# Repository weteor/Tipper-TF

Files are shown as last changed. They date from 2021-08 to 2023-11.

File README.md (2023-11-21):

# Tipper-TF
34 keys split unibody BLE keyboard. 

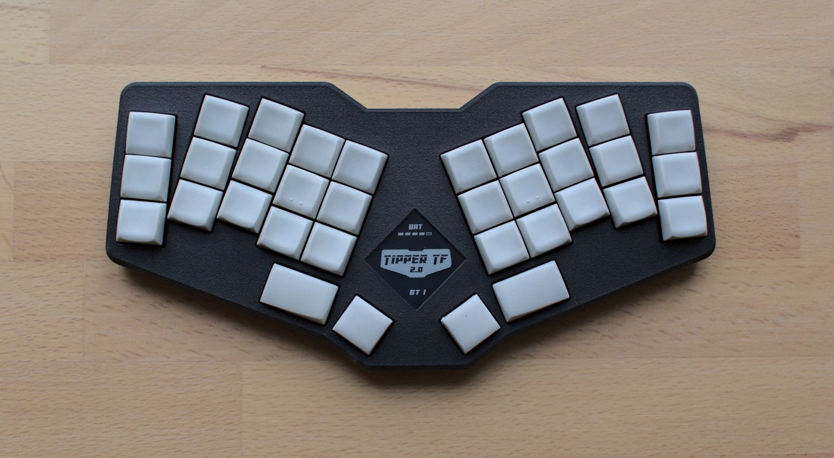
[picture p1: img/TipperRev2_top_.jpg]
top


## Features

- low profile
- choc v1 w/ choc spacing
- angled hands
- splayed columns
- variable height on outer colum. Can be adjusted by a combination of pinheaders(1.27mm pitch, 1mm or 1.5mm height) + (at the moment) spacer pcbs.
- 1.54'' epaper display (Good Display GDEW0154M09)
- Bluetooth and USB connection 
- case files are supplied (stl, as well as freecad files)
- ZMK firmware support

## Want one?
All production files you need to build your own Tipper TF can be found [here](https://github.com/weteor/Tipper-TF/tree/main/production).

Please see the [build instruction](https://github.com/weteor/Tipper-TF/tree/main/production/build_instructions.md) for a more detailed listing of all things needed.

All PCBs come with SMT assembly files, so you can order them fully assembled. No need to solder another 50 diodes.

The files for the case are also provided. If you don't own a 3d printer, I've used JLCPCBs printing service (MJF nylon) and it turned out very good, so maybe take a look at that option.

### firmware 
The Tipper TF uses ZMK firmware.

The zmk driver for the display driver chip is not in the official repository yet, so you will have to use [my ZMK fork](https://github.com/weteor/zmk/tree/Tipper_TF_rev2) if you want to build a firmware locally.

If you prefer the github workflow, you can find the zmk config for the Tipper TF [here](https://github.com/weteor/Tipper_TF-Config). The config is already configured to pull ZMK from my fork, so you don't have to do anything further.

### some more pictures
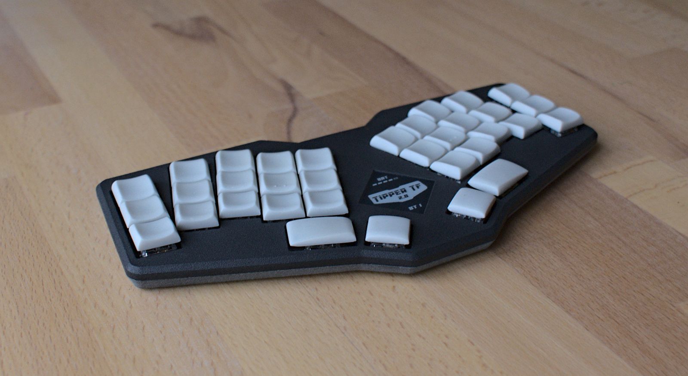
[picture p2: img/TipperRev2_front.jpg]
front

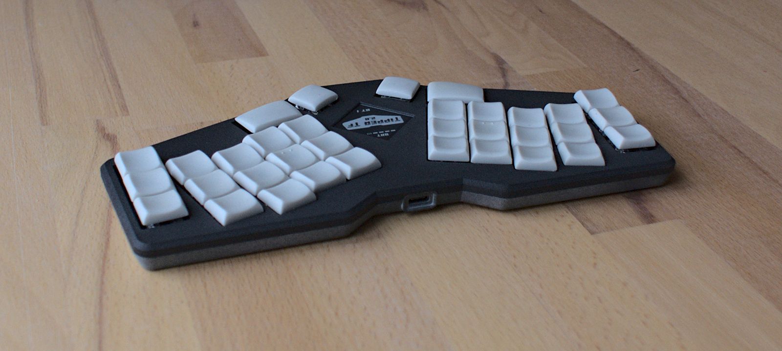
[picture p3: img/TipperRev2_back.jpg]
back


## remarks
MKB keycaps work great on the Tipper, but I very much prefer the Chicago Steno caps by Pseudoku. He provides some nice SCAD files for those, you may find them in [his github](https://github.com/pseudoku/PseudoMakeMeKeyCapProfiles). He also sells them in his shop [www.asymplex.xyz](https://www.asymplex.xyz/).

### thanks for help and inspiration:
- [MangoIV](https://github.com/MangoIV/) and his [le-chiffre-ble](https://github.com/MangoIV/le_chiff_ble)
- [broom's](https://github.com/davidphilipbarr) [hypergolic](https://github.com/davidphilipbarr/hypergolic)
- [marv](https://github.com/MarvFPV) invaluable feedback and help with the case design

## the rest
Everything in this repository is free to use however you might see fit. If you want to support me and my projects, please consider linking back to this repository if you build/change/use anything. 

If you would like to send me a tip, you could do it [here](https://ko-fi.com/weteor) (Please don't feel like you have to).

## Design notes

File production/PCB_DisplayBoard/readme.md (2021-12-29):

## PCB
Gerber and drill files -> [GERBER_DisplayDaughterboardEPD.zip](https://github.com/weteor/Tipper-TF/blob/main/production/PCB_DisplayBoard/GERBER_DisplayDaughterboardEPD.zip)

#### Production Parameters:

- Layers: 2
- PCB Thickness: **1.2mm**
- Dimensions: 44.6 mm* 40.1 mm
- Designs: 1

## SMT Assembly 

The files are specifically made for JLCPCB, but with some small modifications should be usable with every other SMTA service.

BOM file -> [BOM_DisplayDaughterboardEPD.csv](https://github.com/weteor/Tipper-TF/blob/main/production/PCB_DisplayBoard/BOM_DisplayDaughterboardEPD.csv)

component placement file -> [POS_DisplayDaughterboardEPD.csv](https://github.com/weteor/Tipper-TF/blob/main/production/PCB_DisplayBoard/POS_DisplayDaughterboardEPD.csv)

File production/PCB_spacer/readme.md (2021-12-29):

## PCB
Gerber and drill files -> [spacerPcb.zip](https://github.com/weteor/Tipper-TF/blob/main/production/PCB_spacer/spacerPcb.zip)

#### Production Parameters:

- Layers: 2
- PCB Thickness: depends, recommended are at least **0.8mm** and **1.0mm**
- Dimensions: 48 mm* 14 mm
- Designs: 1

## remarks
spacer pcbs can be stacked do get the desired height of the pinky column. I prefer 1.8mm, so i use 0.8 and 1.0mm spacer pcbs. 

Heights up to 2mm can be realized with just pcb spacers. The switches can still be soldered directly on the backside of the main pcb. If a higher level is
needed, you have to use 1.27mm pitched pin headers under the spacer pcb.

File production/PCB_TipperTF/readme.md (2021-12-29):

## PCB
Gerber and drill files -> [TipperTF.zip](https://github.com/weteor/Tipper-TF/blob/main/production/PCB_TipperTF/TipperTF.zip)

#### Production Parameters:

- Layers: 2
- PCB Thickness: **1.2mm**
- Dimensions: 229.6 mm* 104.4 mm
- Designs: 1

## SMT Assembly 

The files are specifically made for JLCPCB, but with some small modifications should be usable with every other SMTA service.

BOM file -> [TipperTF.csv](https://github.com/weteor/Tipper-TF/blob/main/production/PCB_TipperTF/TipperTF.csv)

component placement file -> [TipperTF-top-pos.csv](https://github.com/weteor/Tipper-TF/blob/main/production/PCB_TipperTF/TipperTF-top-pos.csv)

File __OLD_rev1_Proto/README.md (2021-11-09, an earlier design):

# Tipper-TF
34 keys split unibody BLE keyboard. 

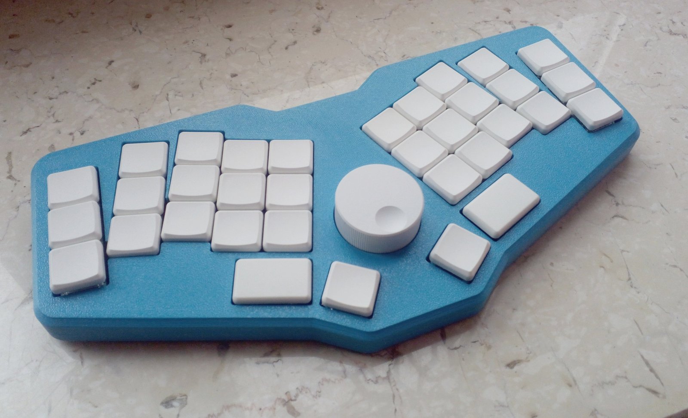
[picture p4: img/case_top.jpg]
front

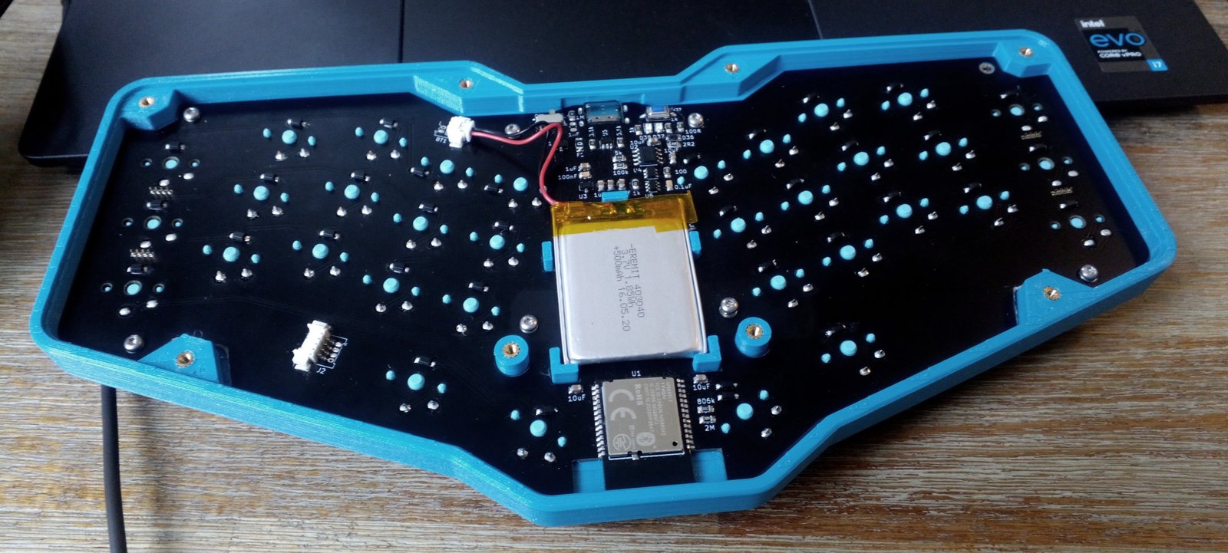
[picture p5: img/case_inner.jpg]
back


- low profile
- choc v1
- central rotary encoder
- angled hands
- splayed columns
- variable height on outer colum. Can be adjusted by a combination of pinheaders(1.27mm pitch, 1mm or 1.5mm height) + (at the moment) 0.8mm spacer pcbs.
- BLE
- case files are supplied

## all files are considered untested prototypes, please don't use them to make your own board just yet. 
At the minimum there is a mismatch between pcb outlines and the case files. pcb needs some small fixes, too

### firmware 
ZMK, config can be found [here](https://github.com/weteor/Tipper_TF-Config)

### thanks for help and inspiration:
- [MangoIV](https://github.com/MangoIV/) and his [le-chiffre-ble](https://github.com/MangoIV/le_chiff_ble)
- [broom's](https://github.com/davidphilipbarr) [hypergolic](https://github.com/davidphilipbarr/hypergolic)
- [marv](https://github.com/MarvFPV) invaluable feedback and help with the case design

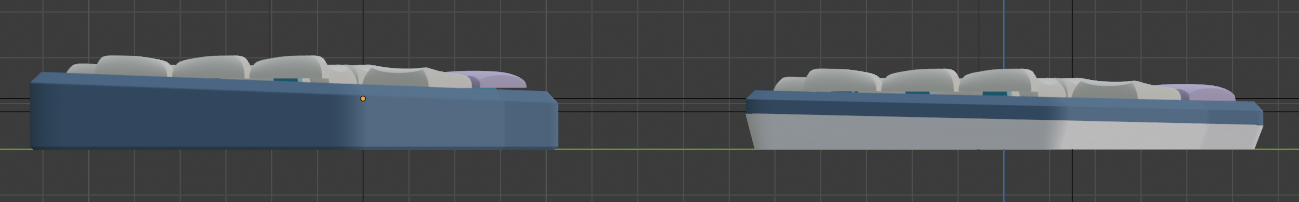
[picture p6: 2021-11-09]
img/proto_rev2_comparison_side.png

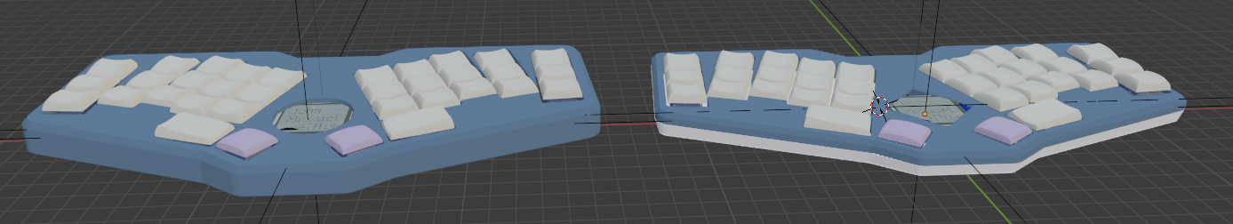
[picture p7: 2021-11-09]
img/proto_rev2_comparison_front_2.png

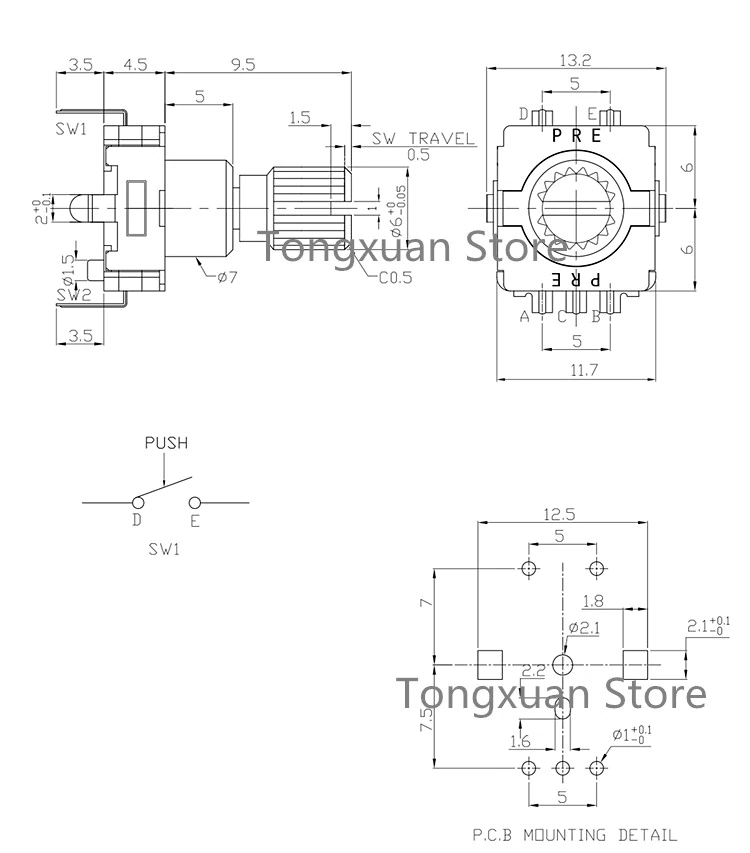
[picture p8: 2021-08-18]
docs/EncoderPlume.webp

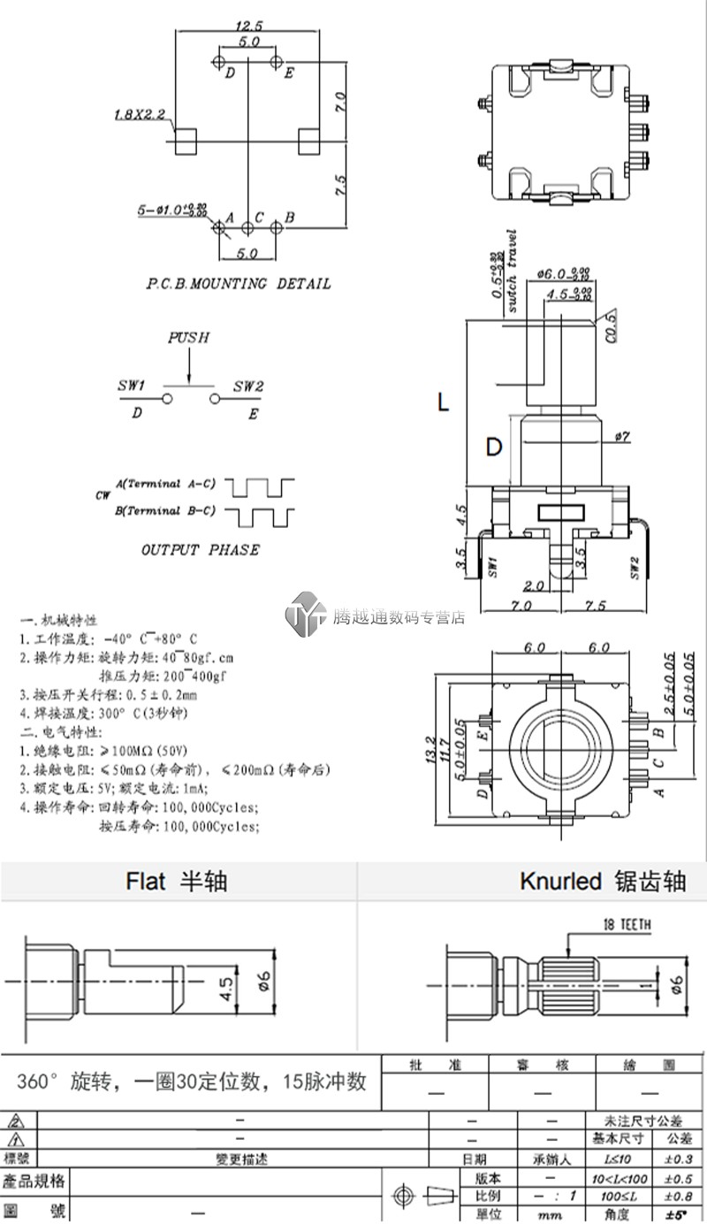
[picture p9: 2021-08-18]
docs/Encoder_ec11_half_shaft_10mm.jpg

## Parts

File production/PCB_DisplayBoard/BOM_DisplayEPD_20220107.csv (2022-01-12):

Comment | Designator | Footprint | LCSC
1uF | C1,C4,C5,C6,C7,C8,C9,C10,C11,C12 | Capacitor_SMD:C_0603_1608Metric | C91185
10uF | C2 | Capacitor_SMD:C_0603_1608Metric | C40894
4.7uF | C3 | Capacitor_SMD:C_0603_1608Metric | C19666
MBR0530 | D1,D2,D3 | Diode_SMD:D_SOD-123 | C77336
Conn_01x10_Female | J1 | weteor:FCC 1x10 - JUSHUO AFC01-S10FCA-00 | C262557
Conn_01x24_Female | J2 | Connector_FFC-FPC:TE_2-1734839-4_1x24-1MP_P0.5mm_Horizontal | C262292
10uH | L1 | Inductor_SMD:L_1210_3225Metric | C86073
AO3400A | Q1 | Package_TO_SOT_SMD:SOT-23 | C347476
0.47R | R1 | Resistor_SMD:R_0603_1608Metric | C23411
1M | R2 | Resistor_SMD:R_0603_1608Metric | C22935
10k | R3 | Resistor_SMD:R_0603_1608Metric | C25804
10R | R4 | Resistor_SMD:R_0603_1608Metric | C228118

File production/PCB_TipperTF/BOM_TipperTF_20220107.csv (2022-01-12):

Comment | Designator | Footprint | LCSC
10uF | C1,C2,C3,C7 | Capacitor_SMD:C_0805_2012Metric | C440198
1nF | C11 | Capacitor_SMD:C_0805_2012Metric | C94121
4.7uF | C4,C5 | Capacitor_SMD:C_0805_2012Metric | C1779
1uF | C6,C8 | Capacitor_SMD:C_0805_2012Metric | C24123
100nF | C9,C10 | Capacitor_SMD:C_0805_2012Metric | C49678
D | D1,D2,D3,D4,D5,D6,D7,D8,D9,D10,D11,D12,D13,D14,D15,D16,D17,D18,D19,D20,D21,D22,D23,D24,D25,D26,D27,D28,D29,D30,D31,D32,D33,D34 | Weteor:D_SOD-123 | C2099
D_Schottky_Small | D36 | Diode_SMD:D_SOD-323_HandSoldering | C172430
gween | D37 | Diode_SMD:D_0805_2012Metric | C142303
oragne | D38 | Diode_SMD:D_0805_2012Metric | C72037
500mA | F1 | Fuse:Fuse_1206_3216Metric | C135336
Conn_01x10 | J7 | Weteor:FCC 1x10 - JUSHUO AFC01-S10FCA-00 | C262557
AO3401A | Q1 | Package_TO_SOT_SMD:SOT-23 | C347476
806k | R1 | Resistor_SMD:R_0805_2012Metric_Pad1.20x1.40mm_HandSolder | C63494
100R | R10,R15 | Resistor_SMD:R_0805_2012Metric_Pad1.20x1.40mm_HandSolder | C422876
1k | R12,R13,R16 | Resistor_SMD:R_0805_2012Metric_Pad1.20x1.40mm_HandSolder | C25623
5k | R5,R6,R14 | Resistor_SMD:R_0805_2012Metric_Pad1.20x1.40mm_HandSolder | C26023
2M | R2 | Resistor_SMD:R_0805_2012Metric_Pad1.20x1.40mm_HandSolder | C40088
1M | R3 | Resistor_SMD:R_0805_2012Metric_Pad1.20x1.40mm_HandSolder | C17514
100k | R7 | Resistor_SMD:R_0805_2012Metric_Pad1.20x1.40mm_HandSolder | C149504
2R2 | R8 | Resistor_SMD:R_0805_2012Metric_Pad1.20x1.40mm_HandSolder | C17521
SW_RESET | SW37 | Weteor:Micro_Push_Button_3x6x2.5mm | C520860
ON_OFF | SW4 | Weteor:K3-2380S-E1 On-on | C145837
TP4056 | U2 | Weteor:TP4056_SOP-8-PP | C16581
XC6206PxxxMR-Regulator_Linear | U3 | Package_TO_SOT_SMD:SOT-23 | C5446
DW01A | U4 | Package_TO_SOT_SMD:SOT-23-6 | C351410
FS8205 | U5 | Package_TO_SOT_SMD:SOT-23-6 | C2830320
USBLC6-2SC6 | U6 | Package_TO_SOT_SMD:SOT-23-6 | C2827654

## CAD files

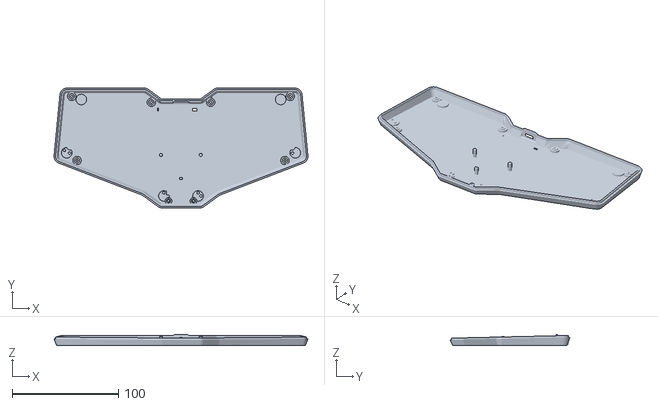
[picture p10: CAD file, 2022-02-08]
production/3DP_case/Tipper_case_FDM_Bottom.stl
239.5 x 113.1 x 10.5

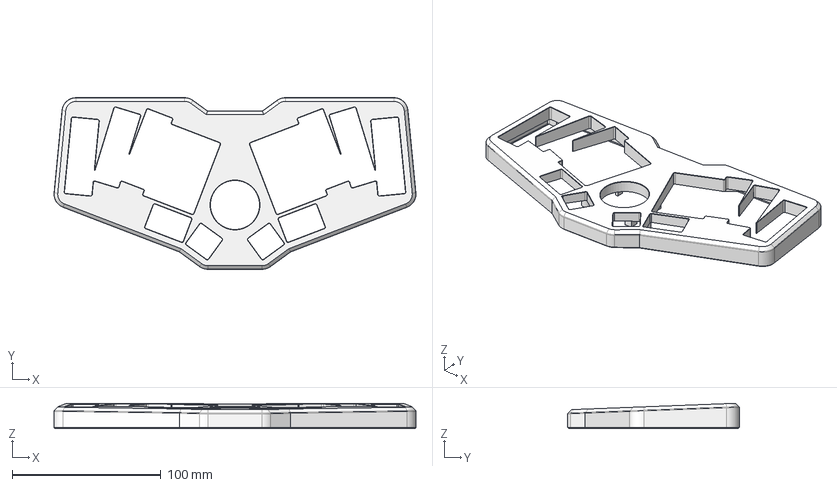
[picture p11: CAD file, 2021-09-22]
production/case/casetop.step
243.5 x 115.5 x 17.1 mm

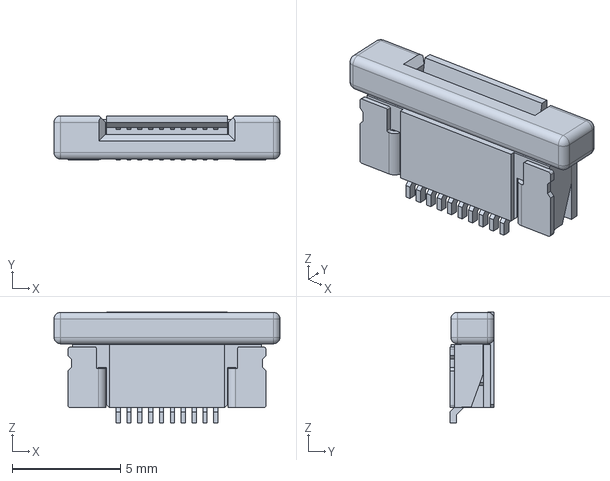
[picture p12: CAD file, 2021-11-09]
pcb/part_library/c-1-1734839-0-c-3d.stp
10.4 x 2.05 x 5.11 mm

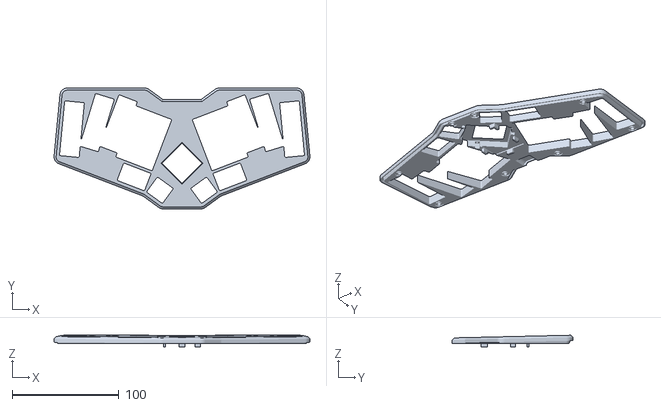
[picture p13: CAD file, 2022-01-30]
production/3DP_case/Tipper_case_Top.stl
239.5 x 113.1 x 10.8

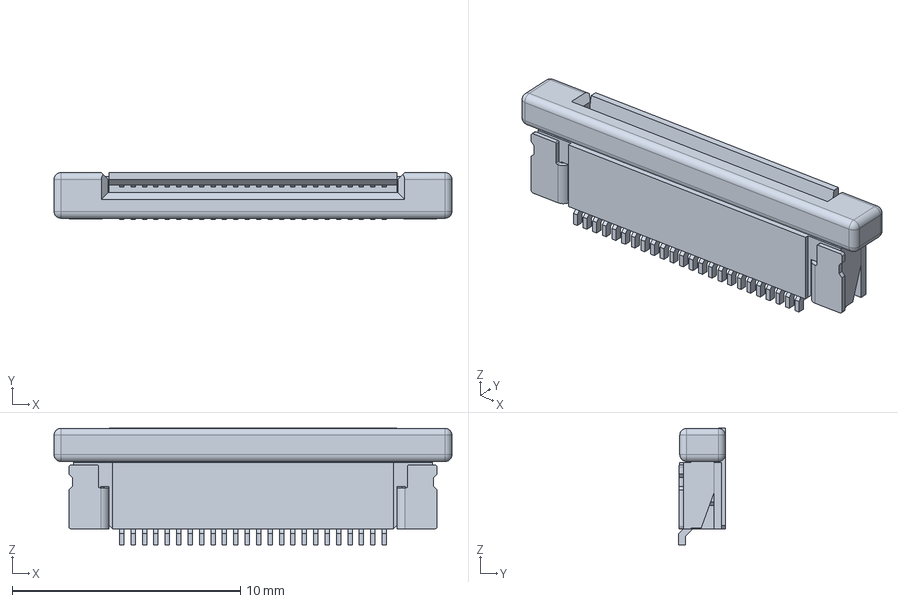
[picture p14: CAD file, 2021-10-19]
pcb/part_library/c-2-1734839-4-c-3d.stp
17.4 x 2.05 x 5.11 mm

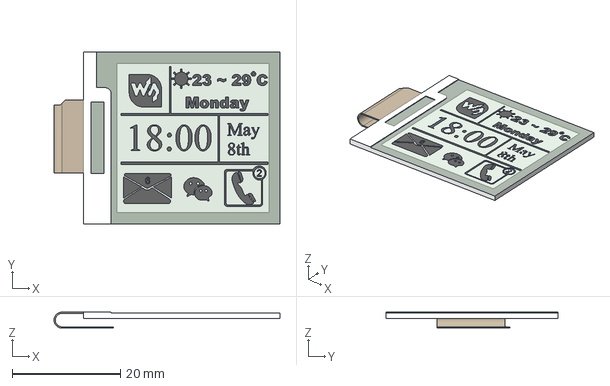
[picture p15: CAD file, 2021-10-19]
pcb/part_library/Waveshare 1.54 E ink - Display Folded.stp
41.8 x 31.8 x 2.92 mm

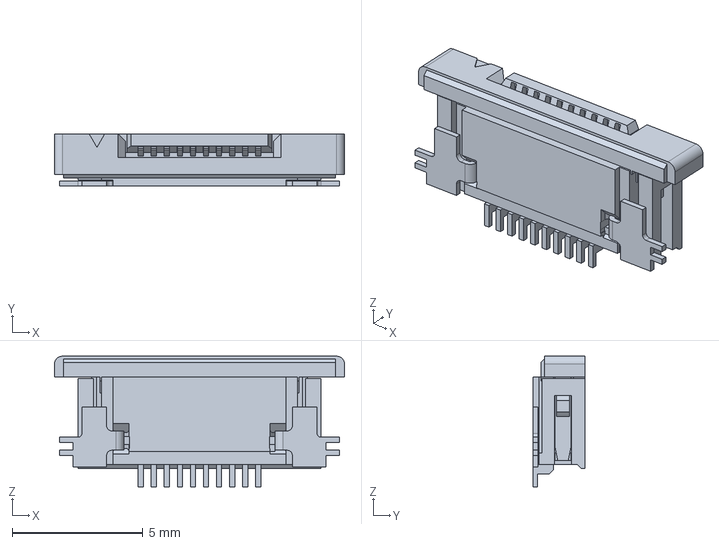
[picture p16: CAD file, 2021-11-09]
pcb/part_library/527451097.stp
11.1 x 2.00 x 5.00 mm

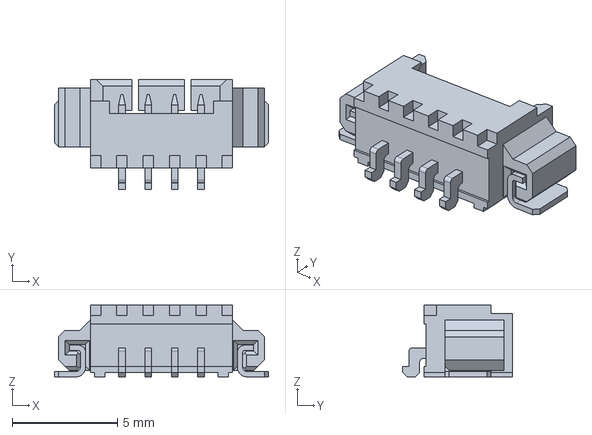
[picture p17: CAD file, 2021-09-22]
pcb/part_library/532610471.stp
10.1 x 5.20 x 3.40 mm

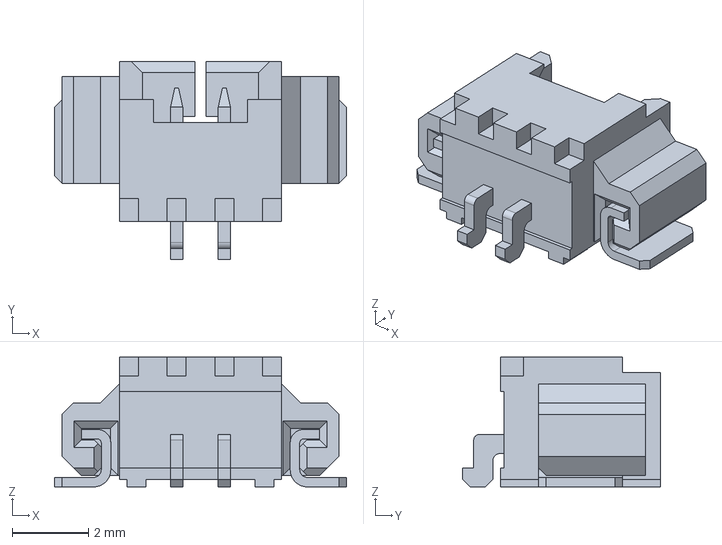
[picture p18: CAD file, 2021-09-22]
pcb/part_library/532610271.stp
7.65 x 5.20 x 3.40 mm

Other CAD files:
production/3DP_case/Tipper_case_Bottom.stl
__OLD_rev1_Proto/production/case/casetop.stl
production/case/casetop.stl

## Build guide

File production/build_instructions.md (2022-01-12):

# build instructions

## what do you need?

#### parts
| # | name | comments |
| --- | --- | --- |
| 1 | main PCB | [gerber and SMT Assembly files](https://github.com/weteor/Tipper-TF/tree/main/production/PCB_TipperTF) |
| 1 | display PCB | [gerber and SMT Assembly files](https://github.com/weteor/Tipper-TF/tree/main/production/PCB_DisplayBoard) |
| 4-8 | spacer PCB | [gerber and SMT Assembly files](https://github.com/weteor/Tipper-TF/tree/main/production/PCB_spacer) |
| 1 | minew ms88sf2 | BT Module |
| 1 | USB connector | USB C, 16 pin, mid mount, 1.6mm bottom to pins |
| 1 | EPD - GDEW0154M09 | 1.54'' E-paper Display by GoodDisplay |
| 1 | 10pin, 0.5mm pitch FCP cable | same side contacts, 8cm recommended, 10cm works |
| 1 | LiPo Battery (403040) | 500mAh, 40x30x4mm, for your own safety, please use one with build in protection circuits |
| 1 | case top | [3DP files](https://github.com/weteor/Tipper-TF/tree/main/production/3DP_case) |
| 1 | case bottom | [3DP files](https://github.com/weteor/Tipper-TF/tree/main/production/3DP_case) |
| 8 | heat inserts m2 | holes are 3.2mm diameter |
| 8 | 6mm m2 screws | min. 4mm |
| 34  | Kailh Choc V1 switch | |
| 32  | keycaps 1u | choc spaced (18x17mm) |
| 2 | keycaps 1.5u | choc spaced (27x17mm) |
| 6 | bumpons | 8mm diameter |
| 16  | o rings | OPTIONAL - can be used between case and pcb |

#### tools
- soldering iron
- double sided tape
- programmer to load bootloader to ms88sf2. J-Link or similar for STM32.
- bootloader - I used the Adafruit bootloader (see my fork)

## prebuild
- check all assembled pcbs for any obvious errors like missing parts etc.
- check if the power button is set to off
- build the bootloader 
- build a zmk firmware
- use the solder iron to place the heat inserts into the case top

## build 
### main pcb
- solder the minew MS88SF2 modulet to the main pcb
- connect the main pcb 
- program bootloader to MS88SF2. You don't need to solder a pin header to the pcb. just connect the cable to a pin header, press it in the holes and angle slightly. This should give enough contact to be able to program the module.
- The tipper should appear in the file manager. If not try pressing the resetbutton twice in a short time, this should restart the module in bootloader mode. If nothing happens try to reboot your PC and try again.
- copy the zmk firmware to the tipper tf drive
- open an editor and test all keys by shortening the contacts (use your tweezers, bend paperclip etc.).
- unplug the pcb
- solder in the switches
- solder the battery cables to the pcb
- plug in the usb cable again and check if the battery loads.
- let the battery load for a bit and unplug the usb cable.
- connect the display to the Displaypcb and connect that to the main pcb with the FCP cable
- turn on the board and see if the display resets and shows the programmed image.
- everything fine? great that's it for this, make sure the pcb is turned off and on to preparing the display.

### display PCB
- connect the display to the display pcb.
- put double sided tape on the side without components.
- allign the display along the lines on the back of the pcb and slightly attach it to the tape. Be careful not to press too hard, you might want to change the position of the display.
- put everything in the case top. There are small pins that should fit right into the holes of the pcb. Space for the Display cable might be tight, but it should fit.
- check if the display sits in the center of the front opening (might be good to program connect the display to the main pcb and program a dark image to it to better see the display area).
- if your are satisfied, firmly attach the display to the tape.

### case
- place the display in the top case.
- _optional_: place O rings in the recesses around the heat insert
- place the main PCB on hte top case, align the screw holes and connect the FCP cable to the pcb. 
- place the battery in the hole over the minew module. the FCP cable should be coming out left of the battery. If it is too long to sit flat, try to tuck away the excess cable under the battery.
- make sure the battery cables can't be pierced by the switch legs or other components. I like to fix them in place with a bit of tape
- _optional_: place O rings in the recesses around the screw holes of the bottom case
- place the bottom half over the top case and screw them together with 2 or 3 screws
- add keycaps and make sure everything works without touching the case. There is a bit of wiggle room for the screws so if something scratches, loosen the screws a bit and try to push/pull the pcb a bit.
- insert the remaining screws
- glue the bumpuns in the recesses

Congratulations, you should have a functioning Tipper TF laying before you :).

Hope you will enjoy the board!

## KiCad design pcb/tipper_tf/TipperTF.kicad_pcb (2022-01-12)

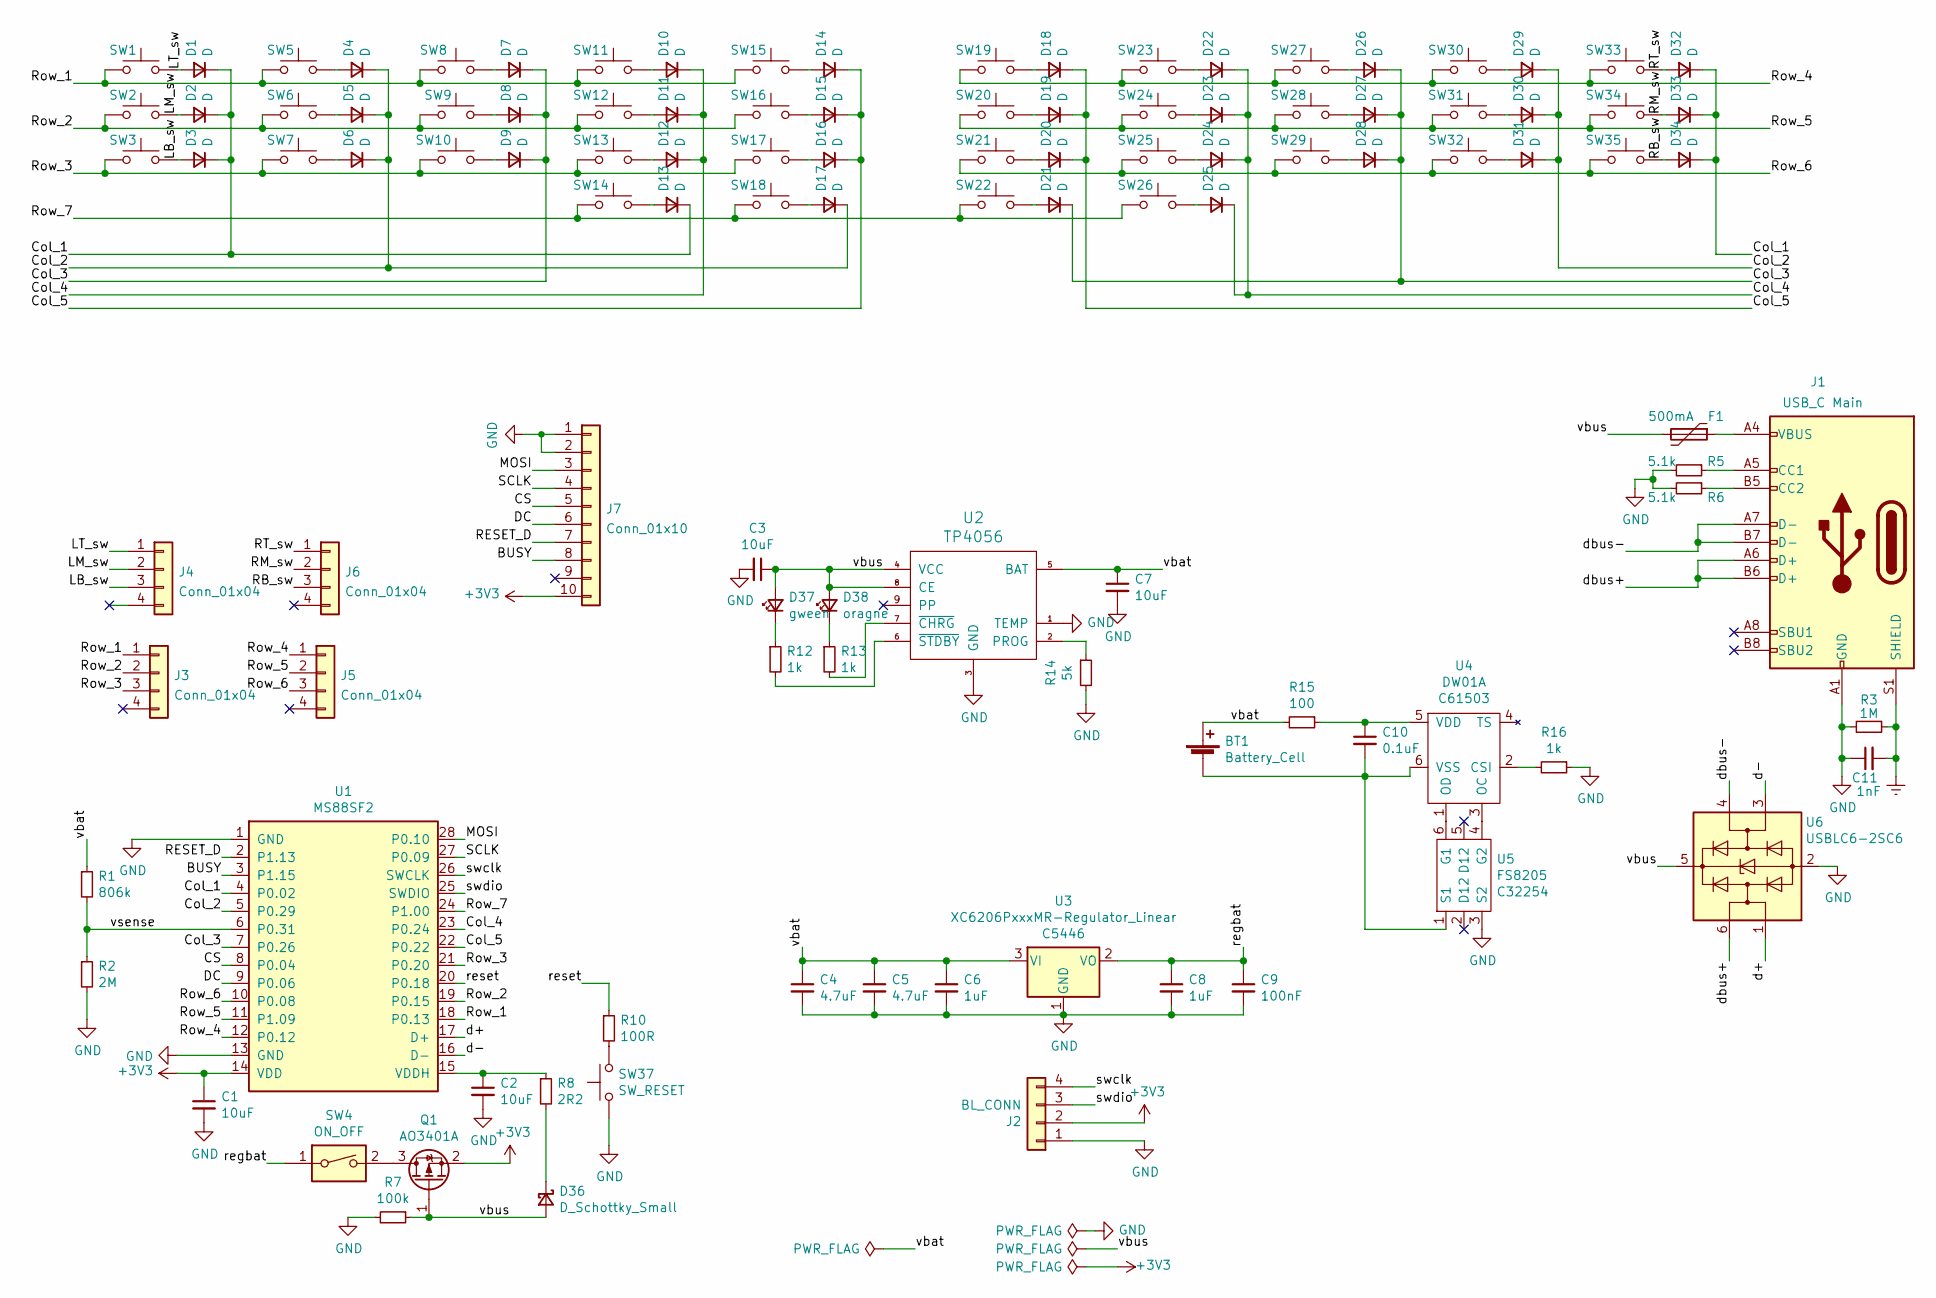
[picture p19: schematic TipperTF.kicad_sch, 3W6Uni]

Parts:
BT1: Battery_Cell; PinHeader_1x02_P2.54mm_Vertical
C1, C2, C3, C7: 10uF; C_0805_2012Metric
C4, C5: 4.7uF; C_0805_2012Metric
C6, C8: 1uF; C_0805_2012Metric
C9: 100nF; C_0805_2012Metric
C10: 0.1uF; C_0805_2012Metric
C11: 1nF; C_0805_2012Metric
D1, D2, D3, D4, D5, D6, D7, D8, D9, D10, D11, D12, D13, D14, D15, D16, D17, D18, D19, D20, D21, D22, D23, D24, D25, D26, D27, D28, D29, D30, D31, D32, D33, D34: D; D_SOD-123
D36: D_Schottky_Small; D_SOD-323_HandSoldering
D37: gween; D_0805_2012Metric
D38: oragne; D_0805_2012Metric
F1: 500mA; Fuse_1206_3216Metric
J1: USB_C Main; USB-C-12-Pin-MidMount
J2: BL_CONN; PinHeader_1x04_P2.54mm_Vertical
J3, J4, J5, J6: Conn_01x04; PinHeader_1x04_P1.27mm_Vertical
J7: Conn_01x10; FCC 1x10 - JUSHUO AFC01-S10FCA-00
Q1: AO3401A; SOT-23
R1: 806k; R_0805_2012Metric_Pad1.20x1.40mm_HandSolder
R2: 2M; R_0805_2012Metric_Pad1.20x1.40mm_HandSolder
R3: 1M; R_0805_2012Metric_Pad1.20x1.40mm_HandSolder
R5, R6: 5.1k; R_0805_2012Metric_Pad1.20x1.40mm_HandSolder
R7: 100k; R_0805_2012Metric_Pad1.20x1.40mm_HandSolder
R8: 2R2; R_0805_2012Metric_Pad1.20x1.40mm_HandSolder
R10: 100R; R_0805_2012Metric_Pad1.20x1.40mm_HandSolder
R12, R13, R16: 1k; R_0805_2012Metric_Pad1.20x1.40mm_HandSolder
R14: 5k; R_0805_2012Metric_Pad1.20x1.40mm_HandSolder
R15: 100; R_0805_2012Metric_Pad1.20x1.40mm_HandSolder
SW1, SW2, SW3, SW5, SW6, SW7, SW8, SW9, SW10, SW11, SW12, SW13, SW15, SW16, SW17, SW18, SW19, SW20, SW21, SW22, SW23, SW24, SW25, SW27, SW28, SW29, SW30, SW31, SW32, SW33, SW34, SW35: SW_Push; Kailh_Choc_1u
SW4: ON_OFF; K3-2380S-E1 On-on
SW14, SW26: SW_Push; Kailh_Choc_1.5u
SW37: SW_RESET; Micro_Push_Button_3x6x2.5mm
U1: MS88SF2; MINEW_MS88SF2
U2: TP4056; TP4056_SOP-8-PP
U3: XC6206PxxxMR-Regulator_Linear; SOT-23; LCSC C5446
U4: DW01A; SOT-23-6; LCSC C61503
U5: FS8205; SOT-23-6; LCSC C32254
U6: USBLC6-2SC6; SOT-23-6

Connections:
+3V3: C1.1, J2.2, J7.10, Q1.2 (S), U1.14 (VDD)
/BUSY: J7.8, U1.3 (P1.15)
/CS: J7.5, U1.8 (P0.04)
/Col_1: D1.1 (K), D2.1 (K), D3.1 (K), D13.1 (K), D32.1 (K), D33.1 (K), D34.1 (K), U1.4 (P0.02)
/Col_2: D4.1 (K), D5.1 (K), D6.1 (K), D17.1 (K), D29.1 (K), D30.1 (K), D31.1 (K), U1.5 (P0.29)
/Col_3: D7.1 (K), D8.1 (K), D9.1 (K), D21.1 (K), D26.1 (K), D27.1 (K), D28.1 (K), U1.7 (P0.26)
/Col_4: D10.1 (K), D11.1 (K), D12.1 (K), D22.1 (K), D23.1 (K), D24.1 (K), D25.1 (K), U1.23 (P0.24)
/Col_5: D14.1 (K), D15.1 (K), D16.1 (K), D18.1 (K), D19.1 (K), D20.1 (K), U1.22 (P0.22)
/DC: J7.6, U1.9 (P0.06)
/LB_sw: D3.2 (A), J4.3, SW3.2
/LM_sw: D2.2 (A), J4.2, SW2.2
/LT_sw: D1.2 (A), J4.1, SW1.2
/MOSI: J7.3, U1.28 (P0.10)
/RB_sw: D34.2 (A), J6.3, SW35.2
/RESET_D: J7.7, U1.2 (P1.13)
/RM_sw: D33.2 (A), J6.2, SW34.2
/RT_sw: D32.2 (A), J6.1, SW33.2
/Row_1: J3.1, SW1.1, SW5.1, SW8.1, SW11.1, SW15.1, U1.18 (P0.13)
/Row_2: J3.2, SW2.1, SW6.1, SW9.1, SW12.1, SW16.1, U1.19 (P0.15)
/Row_3: J3.3, SW3.1, SW7.1, SW10.1, SW13.1, SW17.1, U1.21 (P0.20)
/Row_4: J5.1, SW19.1, SW23.1, SW27.1, SW30.1, SW33.1, U1.12 (P0.12)
/Row_5: J5.2, SW20.1, SW24.1, SW28.1, SW31.1, SW34.1, U1.11 (P1.09)
/Row_6: J5.3, SW21.1, SW25.1, SW29.1, SW32.1, SW35.1, U1.10 (P0.08)
/Row_7: SW14.1, SW18.1, SW22.1, SW26.1, U1.24 (P1.00)
/SCLK: J7.4, U1.27 (P0.09)
/d+: U1.17 (D+), U6.1 (I/O1)
/d-: U1.16 (D-), U6.3 (I/O2)
/dbus+: J1.A6 (D+), J1.B6 (D+), U6.6 (I/O1)
/dbus-: J1.A7 (D-), J1.B7 (D-), U6.4 (I/O2)
/regbat: C8.1, C9.1, SW4.1, U3.2 (VO)
/reset: R10.1, U1.20 (P0.18)
/swclk: J2.4, U1.26 (SWCLK)
/swdio: J2.3, U1.25 (SWDIO)
/vbat: BT1.1 (+), C4.1, C5.1, C6.1, C7.1, R1.1, R15.2, U2.5 (BAT), U3.3 (VI)
/vbus: C3.1, D36.2 (A), D37.2 (A), D38.2 (A), F1.2, Q1.1 (G), R7.1, U2.4 (VCC), U2.8 (CE), U6.5 (VBUS)
/vsense: R1.2, R2.1, U1.6 (P0.31)
Earth: C11.2, J1.S1 (SHIELD), R3.1
GND: C1.2, C2.2, C3.2, C4.2, C5.2, C6.2, C7.2, C8.2, C9.2, C11.1, J1.A1 (GND), J1.A12 (GND), J1.B1 (GND), J1.B12 (GND), J2.1, J7.1, J7.2, R2.2, R3.2, R5.2, R6.2, R7.2, R14.2, R16.1, SW37.1, U1.1 (GND), U1.13 (GND), U2.1 (TEMP), U2.3 (GND), U3.1 (GND), U5.3 (S2), U6.2 (GND)
unnamed: BT1.2 (-), C10.2, U4.6 (VSS), U5.1 (S1)
unnamed: C2.1, R8.1, U1.15 (VDDH)
unnamed: C10.1, R15.1, U4.5 (VDD)
unnamed: D4.2 (A), SW5.2
unnamed: D5.2 (A), SW6.2
unnamed: D6.2 (A), SW7.2
unnamed: D7.2 (A), SW8.2
unnamed: D8.2 (A), SW9.2
unnamed: D9.2 (A), SW10.2
unnamed: D10.2 (A), SW11.2
unnamed: D11.2 (A), SW12.2
unnamed: D12.2 (A), SW13.2
unnamed: D13.2 (A), SW14.2
unnamed: D14.2 (A), SW15.2
unnamed: D15.2 (A), SW16.2
unnamed: D16.2 (A), SW17.2
unnamed: D17.2 (A), SW18.2
unnamed: D18.2 (A), SW19.2
unnamed: D19.2 (A), SW20.2
unnamed: D20.2 (A), SW21.2
unnamed: D21.2 (A), SW22.2
unnamed: D22.2 (A), SW23.2
unnamed: D23.2 (A), SW24.2
unnamed: D24.2 (A), SW25.2
unnamed: D25.2 (A), SW26.2
unnamed: D26.2 (A), SW27.2
unnamed: D27.2 (A), SW28.2
unnamed: D28.2 (A), SW29.2
unnamed: D29.2 (A), SW30.2
unnamed: D30.2 (A), SW31.2
unnamed: D31.2 (A), SW32.2
unnamed: D36.1 (K), R8.2
unnamed: D37.1 (K), R12.1
unnamed: D38.1 (K), R13.1
unnamed: F1.1, J1.A4 (VBUS), J1.A9 (VBUS), J1.B4 (VBUS), J1.B9 (VBUS)
unnamed: J1.A5 (CC1), R5.1
unnamed: J1.B5 (CC2), R6.1
unnamed: Q1.3 (D), SW4.2
unnamed: R10.2, SW37.2
unnamed: R12.2, U2.6 (~STDBY)
unnamed: R13.2, U2.7 (~CHRG)
unnamed: R14.1, U2.2 (PROG)
unnamed: R16.2, U4.2 (CSI)
unnamed: U4.1 (OD), U5.6 (G1)
unnamed: U4.3 (OC), U5.4 (G2)

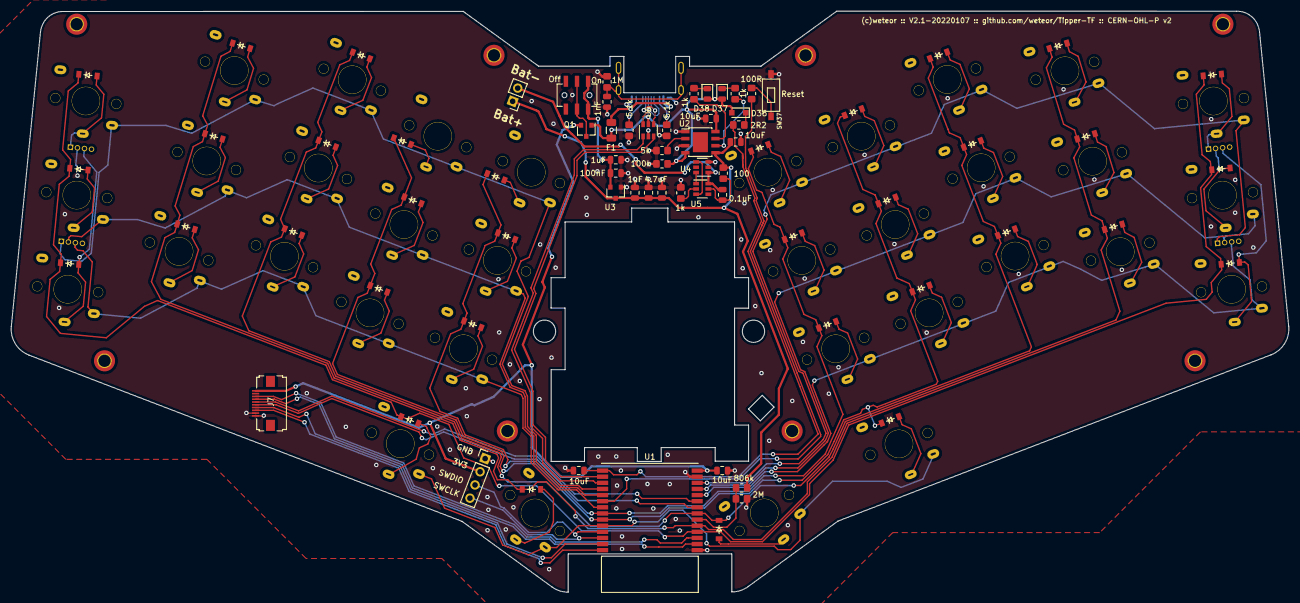
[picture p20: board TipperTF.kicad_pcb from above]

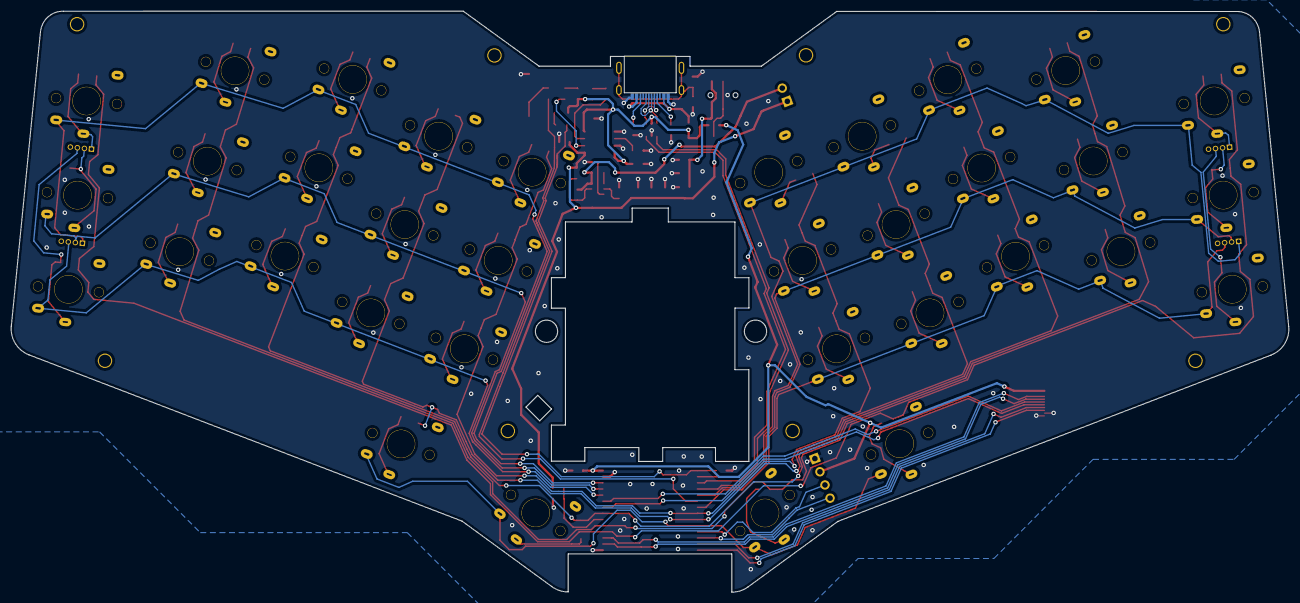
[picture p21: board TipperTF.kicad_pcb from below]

Board: 2 copper layers, 229.6 x 104.4 mm, 113 parts (39 on the bottom side), 83 nets.

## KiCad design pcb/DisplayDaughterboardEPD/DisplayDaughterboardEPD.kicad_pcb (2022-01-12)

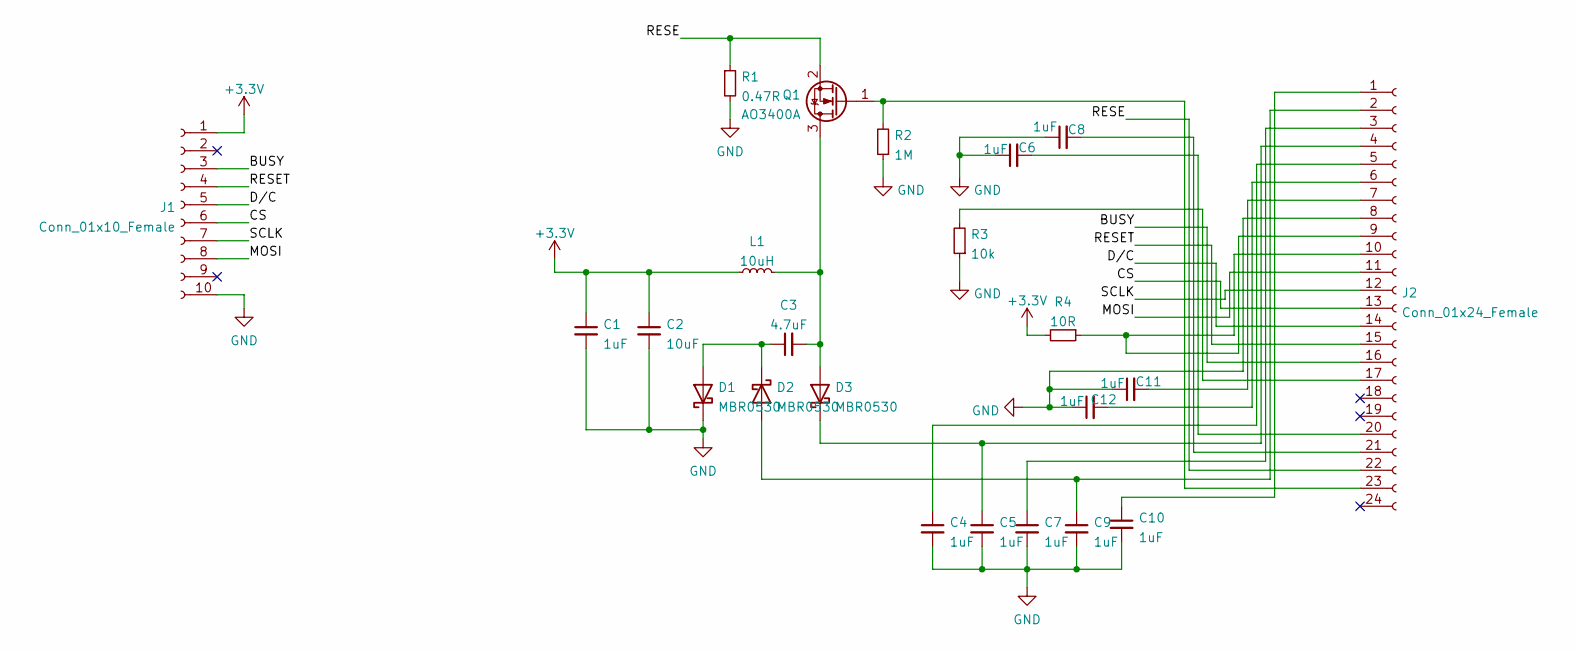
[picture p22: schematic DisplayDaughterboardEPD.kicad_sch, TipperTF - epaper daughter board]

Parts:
C1, C4, C5, C6, C7, C8, C9, C10, C11, C12: 1uF; C_0603_1608Metric
C2: 10uF; C_0603_1608Metric
C3: 4.7uF; C_0603_1608Metric
D1, D2, D3: MBR0530; D_SOD-123
J1: Conn_01x10_Female; FCC 1x10 - JUSHUO AFC01-S10FCA-00
J2: Conn_01x24_Female; TE_2-1734839-4_1x24-1MP_P0.5mm_Horizontal
L1: 10uH; L_1210_3225Metric
Q1: AO3400A; SOT-23
R1: 0.47R; R_0603_1608Metric
R2: 1M; R_0603_1608Metric
R3: 10k; R_0603_1608Metric
R4: 10R; R_0603_1608Metric

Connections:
+3V3: C1.1, C2.1, J1.1, L1.1, R4.2
/BUSY: J1.3, J2.16
/CS: J1.6, J2.13
/D/C: J1.5, J2.14
/MOSI: J1.8, J2.11
/RESE: J2.22, Q1.2 (S), R1.1
/RESET: J1.4, J2.15
/SCLK: J1.7, J2.12
GND: C1.2, C2.2, C4.2, C5.2, C6.1, C7.2, C8.1, C9.2, C10.2, C11.1, C12.1, D1.1 (K), J1.10, J2.8, R1.2, R2.1, R3.1
unnamed: C3.1, D1.2 (A), D2.1 (K)
unnamed: C3.2, D3.2 (A), L1.2, Q1.3 (D)
unnamed: C4.1, J2.5
unnamed: C5.1, D3.1 (K), J2.4
unnamed: C6.2, J2.20
unnamed: C7.1, J2.3
unnamed: C8.2, J2.21
unnamed: C9.1, D2.2 (A), J2.2
unnamed: C10.1, J2.1
unnamed: C11.2, J2.7
unnamed: C12.2, J2.6
unnamed: J2.9, J2.10, R4.1
unnamed: J2.17, R3.2
unnamed: J2.23, Q1.1 (G), R2.2

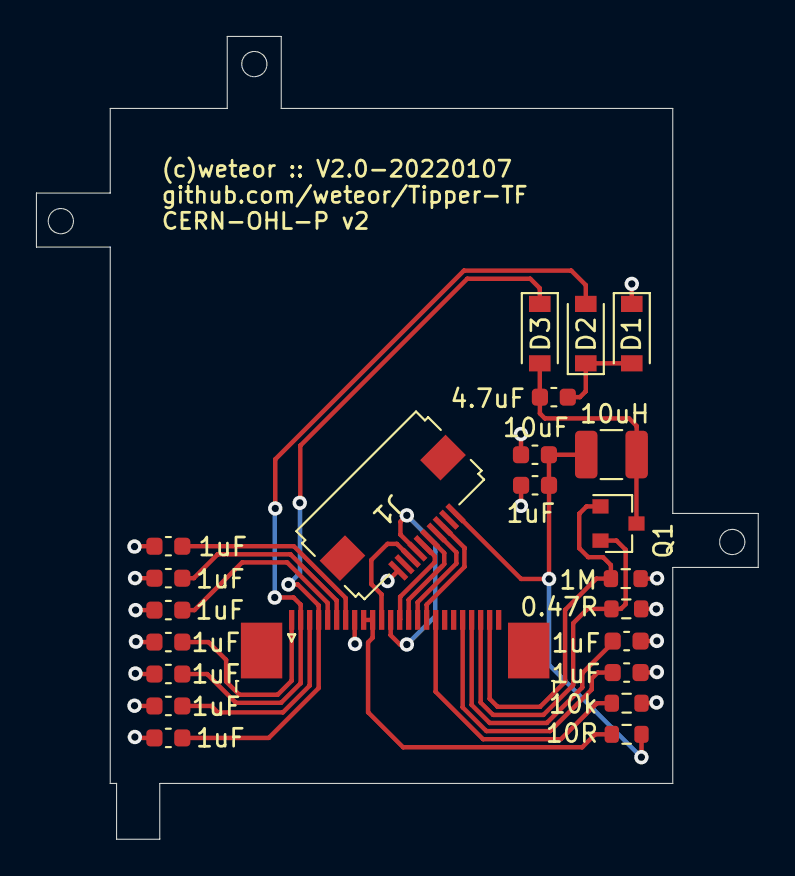
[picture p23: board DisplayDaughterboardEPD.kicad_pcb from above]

Board: 2 copper layers, 40.1 x 44.6 mm, 23 parts (0 on the bottom side), 23 nets.

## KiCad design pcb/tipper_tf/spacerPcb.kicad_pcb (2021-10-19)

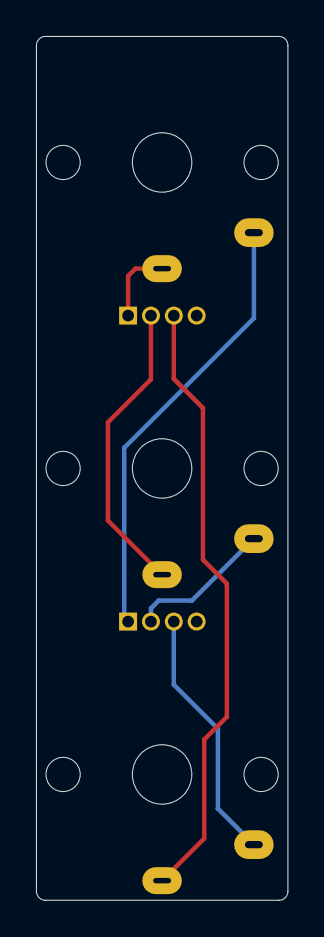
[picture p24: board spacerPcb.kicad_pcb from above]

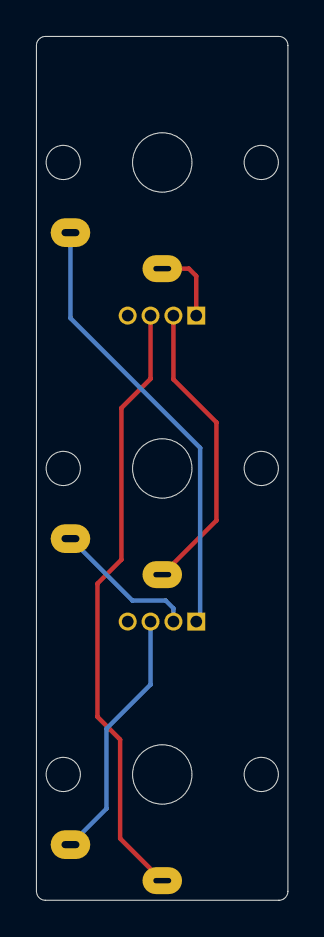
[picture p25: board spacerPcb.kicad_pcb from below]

Board: 2 copper layers, 14.0 x 48.0 mm, 5 parts (5 on the bottom side), 6 nets.

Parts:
J3, J4: Conn_01x04; PinHeader_1x04_P1.27mm_Vertical
SW1, SW2, SW3: SW_Push; Kailh_Choc_1u

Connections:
/LB_sw: J4.3, SW3.2
/LM_sw: J4.2, SW2.2
/LT_sw: J4.1, SW1.2
/Row1: J3.1, SW1.1
/Row2: J3.2, SW2.1
/Row3: J3.3, SW3.1

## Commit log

2021-08-18 encoder docs
2021-08-23 new case function, shorter, using locations
2021-08-25 change config. add screw holes and case bottom
2021-08-26 first version fix: case, pcb
2021-08-26 generated dxf and stl files for v1
    [casebottom.dxf, casebottom.stl, combined.dxf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]
2021-08-26 add initial kicad project and library
    [3W6Uni.kicad_pcb, 3W6Uni.sch]
2021-08-28 new stl dxf files with usbport opening
    [casebottom.stl, combined.dxf, combined_.dxf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]
2021-08-28 add rotary encoder to lib.WIP PCB
    [3W6Uni.kicad_pcb, 3W6Uni.sch]
2021-09-02 add space for battery fix holes and placements
    [combined.dxf, combined_.dxf]
2021-09-02 pcb routed
    [3W6Uni.kicad_pcb, 3W6Uni.kicad_sch]
2021-09-10 case add notch at thumbs
2021-09-10 make pcb ready for manufacturing, add backplate
    [3W6Uni.kicad_pcb, 3W6Uni.kicad_sch, 3W6Uni_back.kicad_pcb]
2021-09-11 new version case
2021-09-11 angled case
2021-09-13 new case angle
2021-09-22 prototype pcb added
    [3W6Uni.kicad_pcb, 3W6Uni.kicad_sch, 3W6Uni.sch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]
2021-09-22 add pcb gerbers and case stl/step
    [casetop.step, casetop.stl]
2021-09-22 add prototype pictures
2021-09-24 add stls and new images
    [casebottom.stl]
2021-10-08 change board outline to match case
2021-10-12 pcb almost ready
    [TipperTF.kicad_sch]
2021-10-19 change: case lower Angle and display cutout
2021-10-19 fix main pcb, new matrix layout, display support, new screwhole positions
    [TipperTF.kicad_sch, Waveshare 1.54 E ink - Display Folded.stp, c-2-1734839-4-c-3d.stp]
2021-10-19 add Display daughterboard
    [DisplayDaughterboardEPD.kicad_pcb, DisplayDaughterboardEPD.kicad_sch]
2021-10-19 change: spacer and backside pcbs changed to reflect changes in case and main pcb
    [TipperTF_back.kicad_pcb, spacerPcb.kicad_pcb]
2021-11-09 daughterboard update for prod rev2
    [DisplayDaughterboardEPD.kicad_pcb, DisplayDaughterboardEPD.kicad_sch]
2021-11-09 pcb update rev2 prod.
    [527451097.stp, TipperTF.kicad_sch, c-1-1734839-0-c-3d.stp]
2021-11-09 move prod data from rev 1
    [casetop.step, casetop.stl]
2021-11-09 change display board to allow for more room above connectors
    [DisplayDaughterboardEPD.kicad_pcb]
2021-11-09 add production data for rev2 proto
    [BOM_DisplayDaughterboardEPD.csv, Positions_DisplayDaughterboardEPD.csv, TipperTF.csv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]
2021-11-09 add freecad sources for case
2021-11-09 move rev 1 to own folder
    [casetop.step, casetop.stl]
2021-12-06 new, hopefully corrected version of displayboard
    [DisplayDaughterboardEPD.kicad_sch, TipperTF.kicad_pcb]
2021-12-06 new production files for display
    [BOM_DisplayDaughterboardEPD.csv, Positions_DisplayDaughterboardEPD.csv]
2021-12-06 unsaved changes
    [DisplayDaughterboardEPD.kicad_pcb, POS_DisplayDaughterboardEPD.csv]
2021-12-28 fix case. reset Button, display cutout
    [Tipper_case_Bottom.stl, Tipper_case_Top.stl]
2021-12-29 readme for main pcb production files
2021-12-29 readme for spacer pcbs
2021-12-29 replaced not in stock Bom components
    [TipperTF.csv]
2021-12-29 replaced non in stock component in Bom for Display board
    [BOM_DisplayDaughterboardEPD.csv]
2022-01-02 add usb connector to build instructions
2022-01-12 fixed bottom case to account for switch legs
2022-01-12 add license print to front silkscreen
    [DisplayDaughterboardEPD.kicad_pcb]
2022-01-12 newest revision of pcb, adds support for choc V2 (WITH CHOC SPACING) and tighening the holes for V1
    [TipperTF.kicad_pcb]
2022-01-12 add production files from latest GB
    [BOM_DisplayDaughterboardEPD.csv, POS_DisplayDaughterboardEPD.csv, TipperTF.csv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]
2022-01-12 add missing production data
    [BOM_DisplayEPD_20220107.csv, BOM_TipperTF_20220107.csv, POSITION_TOP_TipperTF_20220107.csv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]
2022-01-12 add library footprints for combined switches
2022-01-30 case: better screw placement, remove small features for better fdm
    [Tipper_case_Bottom.stl, Tipper_case_Top.stl, Tipper_case_Top_FDM.stl]
2022-02-08 add bottom stl w/ sacrificial planes
    [Tipper_case_FDM_Bottom.stl]
2022-02-08 new version of fdm bottom
    [Tipper_case_FDM_Bottom.stl]

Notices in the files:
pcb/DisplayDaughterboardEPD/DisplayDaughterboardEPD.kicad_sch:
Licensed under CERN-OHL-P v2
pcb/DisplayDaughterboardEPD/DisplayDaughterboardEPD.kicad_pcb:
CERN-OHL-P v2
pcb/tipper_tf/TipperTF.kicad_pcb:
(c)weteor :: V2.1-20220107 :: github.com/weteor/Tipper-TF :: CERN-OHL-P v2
